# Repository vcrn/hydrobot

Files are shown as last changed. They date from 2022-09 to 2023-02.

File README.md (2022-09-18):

`hydrobot`
=======================
Automatic plant watering system using Rust and Arduino Uno.

Once every 24 hours, the system will check the plant's pot for a duration of 3 seconds and water the plant if deemed suitable.

2 sensors are connected to the Arduino, one which measures the moisture of the plant's soil and one which measures the water level in the tray below the pot. There are 3 scenarios:
 - If the moisture sensor sends a too low value to the Arduino, no watering will take place. This is because it indicates that the sensor isn't placed in some conducting surrounding (soil) or is faulty.
 - If the moisture sensor sends a too high value, or the water level sensor in the tray sends a too high value, no watering will take place. This indicates that the soil is moist enough or that water has ended up in the tray, with further watering risking flooding.
 - If the moisture sensor sends a value between the two levels mentioned in previous steps, and the water level sensor in the tray sends a low enough value, watering will take place. The pump will be turned on for a pre-set amount of time.

Upon powering up the system, it will start by checking the plant's pot (and potentially watering the plant), before going to standby. Information will be diplayed on the connected LCD, such as the result from the pot measurements and time left until the next measurement.

# Usage

## Flashing to Arduino
 - First, you need to install Rust (<https://www.rust-lang.org/tools/install>)
 - Second: For Linux or Mac, use this guide to install the necassary tools: <https://book.avr-rust.com/002.1-installing-required-third-party-tools.html>; for Windows, go to the next step and see what tools you are missing, find them and set their paths' as environment variables.
 - Then, install `ravedude`:
 ```bash
 cargo install ravedude
 ```

To flash the Arduino, run
```bash
cargo run
```
in the project root directory. You may need to manually set the port. Either use the Arduino app from arduino.cc to find it, or check it with suitable command, then set it by following the instructions of `ravedude`. This information can be set in `.cargo/config.toml`.

## Building the hardware
The diagram below depicts the complete circuit diagram of the watering system.
<div align="center">
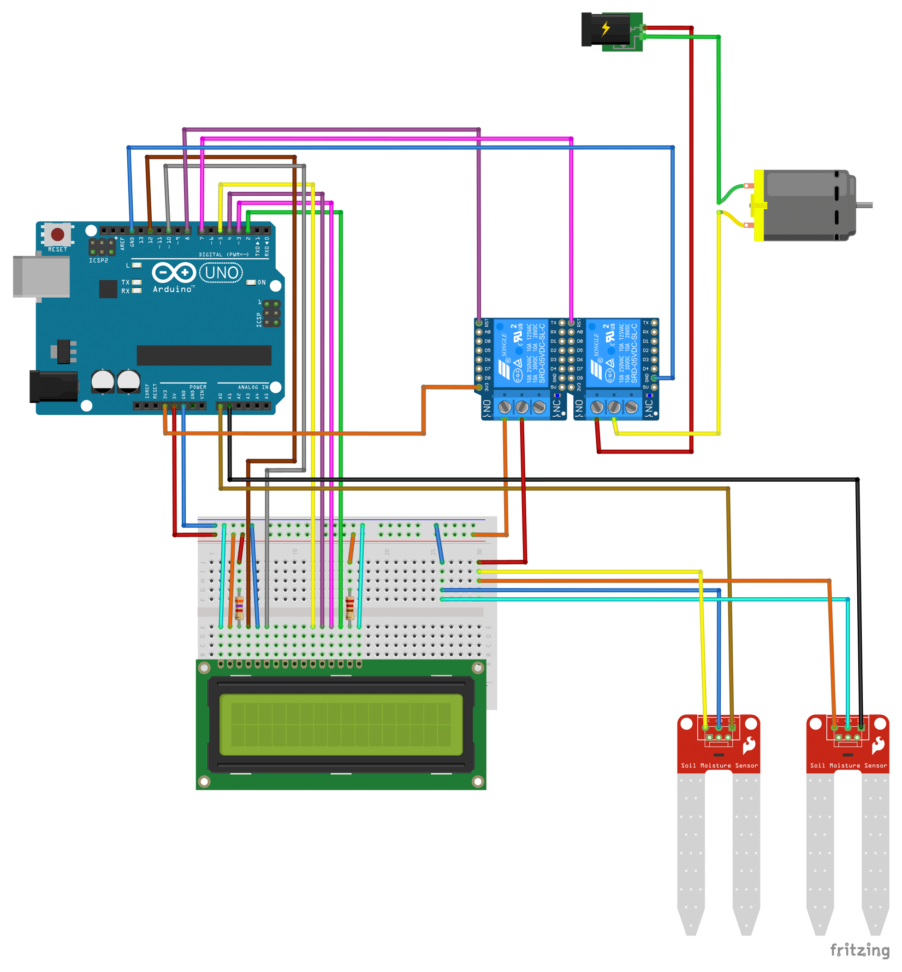
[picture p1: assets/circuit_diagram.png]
Circuit diagram of system.
  
  <p>
    <i>Circuit diagram of system.</i>
  </p>
</div>

Sensors and pump were bought from Whadda. The chip is an Arduino Uno, but other models of Arduino should work too. The LCD is a HITACHI HD44780. The resistor leading to the 3rd of the LCD is 4.7 $\mathsf{k\Omega}$ and the one leading to the 15th is 220 $\mathsf{k\Omega}$.

A solderless breadboard is depicted in the circuit diagram, but this is only done for illustrative reasons. The finished system should be connected in a more robust way.

## Calibrating the system
The system can be tuned by changing how much water the pump approximately moves in mililiters per milisecond, how much water which is to be pumped, for how long time the sensors are to be active per cycle, the lower and upper limits of the moisture sensor, the limit of the water level sensor, and the time between cycles.

## Using other AVR-chips
If the code is to be flashed to another kind of AVR-chip than that of Arduino Uno (ATmega328P), json files corresponding to other chips are available in the `avr-specs/` directory. Target platform can be changed in `.cargo/config.toml` by setting `target` under the `build` section to the chip's json file.

# Tools used for project
## Code
`hydrobot` is built using tools, crates, json files and template from [Rahix](https://github.com/Rahix). It also uses the crate [ag-lcd](https://github.com/mjhouse/ag-lcd) to control the LCD.

## Circuit diagram
Circuit diagram was made using Fritzing. Editable file located at `assets/circuit_diagram.fzz`.

# License
Licensed under GNU General Public License, Version 3.0.

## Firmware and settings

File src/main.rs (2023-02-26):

#![no_std]
#![no_main]
#![allow(unused_imports)]

use ag_lcd::{Display, LcdDisplay};
use arduino_hal::{delay_ms, delay_us};
use panic_halt as _;

// When the Arduino is connected to a computer, text can be printed to the computer screen by
// adding the following lines:
// use arduino_hal::prelude::*;
// let mut serial = arduino_hal::default_serial!(dp, pins, 57600);
// ufmt::uwriteln!(&mut serial, "Printed on computer screen: {} ", t_pump_on).void_unwrap();

#[arduino_hal::entry]
fn main() -> ! {
    arduino_hal::delay_ms(2000);
    // Setting up pins
    let dp = arduino_hal::Peripherals::take().unwrap();
    let pins = arduino_hal::pins!(dp);

    let mut adc = arduino_hal::Adc::new(dp.ADC, Default::default());

    let a0 = pins.a0.into_analog_input(&mut adc); // Pin connected to water sensor
    let a1 = pins.a1.into_analog_input(&mut adc); // Pin connected to moisture sensor

    let mut d8 = pins.d8.into_output(); // Controls water sensor and moisture sensor
    let mut d7 = pins.d7.into_output(); // Controls pump

    // Setting up pins for LCD. Named by "[avr-pin]_[lcd-pin to be connected to]"
    let d12_rs = pins.d12.into_output().downgrade();
    let d10_en = pins.d10.into_output().downgrade();
    let d5_d4 = pins.d5.into_output().downgrade();
    let d4_d5 = pins.d4.into_output().downgrade();
    let d3_d6 = pins.d3.into_output().downgrade();
    let d2_d7 = pins.d2.into_output().downgrade();

    // Setting up LCD
    let delay = arduino_hal::Delay::new();
    let mut lcd: LcdDisplay<_, _> = LcdDisplay::new(d12_rs, d10_en, delay)
        .with_half_bus(d5_d4, d4_d5, d3_d6, d2_d7)
        .with_display(Display::On)
        .with_lines(ag_lcd::Lines::TwoLines)
        .build();

    lcd.ensure_init(); // Initializes the LCD more reliably.

    // Setting sensor value limits
    let water_sensor_limit = 100; // Value above indicates sensor is in contact with water
    let moisture_sensor_lower_limit = 20; // Value below this indicates that moisture sensor is not placed in soil
    let moisture_sensor_dry_soil_limit = 500; // Value below this indicates that soil is dry enough to water

    // User defined parameters regarding pump and how much water which is plant is to be given
    let water_to_plant = 300.; // How much water that is to be pumped, in ml
    let ml_per_ms: f32 = 0.0475; // How much water in ml that is being pumped per ms. Based on measurement of 950 ml during 20 s

    // Calculations regarding time, i.e. time for pump to be turned on, and time until next measurement split into whole minutes and miliseconds
    let t_pump_on = (water_to_plant / ml_per_ms) as u16; // Amount of time that pump is to be running in ms
    let t_sensors_on = 3000; // Time to keep sensors on per measurement
    let t_next_check_ms: u32 = 24 * 60 * 60 * 1000 - (t_pump_on - t_sensors_on) as u32; // (A whole day in miliseconds) - (time for sensors and pump to finish)

    let t_next_check_mins = t_next_check_ms / 60_000;
    let t_next_check_remainder_ms = (t_next_check_ms % 60_000) as u16;

    loop {
        d8.set_high(); // Turns on water sensor
        lcd.clear_print("Water & moisture", "sensors ON");
        delay_ms(t_sensors_on);
        let a0_value = a0.analog_read(&mut adc); // Value from water sensor
        let a1_value = a1.analog_read(&mut adc); // Value from moisture sensor
        d8.set_low(); // Turns off water sensor

        if a1_value < moisture_sensor_lower_limit {
            // Moisture sensor not in soil
            lcd.clear_print("Moisture sensor", "not in soil");
        } else if a0_value < water_sensor_limit && a1_value < moisture_sensor_dry_soil_limit {
            lcd.clear_print("Plant is dry:", "pump ON");
            d7.set_high(); // Turn on pump
        } else {
            lcd.clear_print("Plant has enough", "water: pump OFF");
        }
        delay_ms(t_pump_on); // So all scenarios take an equal amount of time
        d7.set_low(); // Turn off pump, if it was on

        for i in (1..=t_next_check_mins).rev() {
            // Inclusive, and goes from large value to small
            let count_down = CountDown::new(i);
            let mut buffer = [0u8; 9];
            match count_down.to_str(&mut buffer) {
                Ok(time_left_str) => lcd.clear_print("Measures in", time_left_str),
                Err(_) => lcd.clear_print("Error converting", "time to UTF-8"),
            }
            delay_ms(60_000);
        }
        lcd.clear_print("Measures in", "less than 1 min");
        delay_ms(t_next_check_remainder_ms);
    }
}

/// Trait containing extra methods for struct LcdDisplay, defined in dependency.
trait LcdDisplayExtra {
    fn clear_print(&mut self, _first_row: &str, _second_row: &str);
    fn ensure_init(&mut self);
}

impl<T, D> LcdDisplayExtra for LcdDisplay<T, D>
where
    T: embedded_hal::digital::v2::OutputPin<Error = core::convert::Infallible> + Sized,
    D: embedded_hal::blocking::delay::DelayUs<u16> + Sized,
{
    /// Clears the LCD before printing on both lines. Small delays are present between some
    /// actions for more reliable execution. E.g, clearing the screen once in the beginning
    /// is sometimes not enough, neither twice without the delay.
    fn clear_print(&mut self, first_row: &str, second_row: &str) {
        self.clear();
        delay_us(100);
        self.clear();
        self.set_position(0, 0);
        self.print(first_row);
        delay_us(100);
        self.set_position(0, 1);
        self.print(second_row);
        self.set_position(0, 0)
    }

    /// LCDs can be a bit flaky with their normal initialization (via `.build()`). This method  
    /// is run after build to more reliably initialize the LCD.
    fn ensure_init(&mut self) {
        for _ in 0..3 {
            delay_ms(100);
            self.display_off();
            delay_ms(100);
            self.display_on();
        }
    }
}

struct CountDown {
    hours_left: u32,
    mins_left: u32,
}

impl CountDown {
    fn new(total_mins_left: u32) -> CountDown {
        CountDown {
            hours_left: (total_mins_left / 60),
            mins_left: (total_mins_left % 60),
        }
    }

    /// Converts a number to a UTF-8 slice, storing it in a supplied buffer, starting at index 'i-1'
    fn num_to_utf8slice(num: u32, buffer: &mut [u8; 9], mut i: usize) {
        let mut x = num;
        while x > 0 {
            i -= 1;
            let rem = x.rem_euclid(10);
            buffer[i] = rem as u8 + 48;
            x = x.div_euclid(10);
        }
    }

    /// Converts hours and minutes to "[hh]h:[mm]min" str
    ///
    /// # Examples
    ///
    /// ```
    /// let count_down = Countdown{07, 23};
    /// let buffer = [0u8, 9];
    /// let count_down_str = count_down.to_str(&mut buffer);
    /// let expected_result = "07h:23min";
    /// assert_eq!(count_down_str, expected_result);
    /// ```
    fn to_str<'a>(self, buffer: &'a mut [u8; 9]) -> Result<&str, core::str::Utf8Error> {
        if self.hours_left < 100 && self.mins_left < 100 {
            *buffer = [48, 48, 104, 58, 48, 48, 109, 105, 110]; // [0, 0, h, :, 0, 0, m, i, n]
            let mut i = 6; // Starts at 1 index after last '0'
            Self::num_to_utf8slice(self.mins_left, buffer, i);
            i = 2;
            Self::num_to_utf8slice(self.hours_left, buffer, i);
        }
        core::str::from_utf8(&buffer[0..])
    }
}

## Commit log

2022-09-21 Update circuit diagram
    [circuit_diagram.fzz]
2023-01-15 Add extra delay_us() and clear() in print_clear() to make it more reliable
2023-02-26 Fix misspelled method name
    [main.rs]
